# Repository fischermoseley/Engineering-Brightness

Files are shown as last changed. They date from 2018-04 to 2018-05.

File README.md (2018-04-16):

# Engineering-Brightness
1.3 billion people across the world lack a source of artificial lighting, and are unable to safely leave thier homes or do work after dark. Often a rudimentary kerosene lamp is used, but carbon monoxide and combustion byproducts build up in the air, leading to death in some cases. Kerosene is also very expensive, and provides little useful light. 

Engineering Brightnes is a program designed to provide free, safe, and reliable artifical lighting to the world. 

Originally started at Preston Middle School, Colorado Early Colleges Fort Collins is currently prototyping a new design, and the files are available here. The electrical system has been sucessfully prototyped, and the mechanical enclosure is currently under development.

More information is available at http://philanthropic-engineering.org/

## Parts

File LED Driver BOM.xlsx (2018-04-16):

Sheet: Rev A
Part | Value | Device | Package | Description | Digikey PN
IC1 | 2.5V | LM4040DYM3-2.5-TR | SOT-23-3 | 2.5V Reference | 576-1047-1-ND
R1 | 0.1R | CSR1206FTR100 | 1206 | 0.1R Shunt Resistor | CSR1206FTR100CT-ND
R2 | 91k | RC0603JR-0791KL | 0603 | 91k Resistor | 311-91KGRCT-ND
R3 | 10k | RC0603FR-0710KL | 0603 | 10k Resistor | 311-10.0KHRCT-ND
R4 | 1.5k | RNCP0603FTD1K50 | 0603 | 1.5k Resistor | RNCP0603FTD1K50CT-ND
U1 |  | SI4712DY | SO8 | Rail-to-Rail Opamp | SI4712DY-T1-GE3CT-ND
U2 |  | MC3320DR2G | 8SOIC | Rail-to-Rail Opamp | MC33202DR2GOSCT-ND

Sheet: Rev B
Onboard:
Part | Value | Device | Package | Description | Digikey PN | Unit Price | Quantity per Board | Cost per Board | Notes | Link
IC1 | 2.5V | LM4040DYM3-2.5-TR | SOT-23-3 | 2.5V Reference | 576-1047-1-ND | 0.7740 | 1 | 0.7740
R1 | 0.1R | CSR1206FTR100 | 1206 | 0.1R Shunt Resistor | CSR1206FTR100CT-ND | 0.2424 | 1 | 0.2424
R2 | 240k | RMCF0603JT240K | 0603 | 240k Resistor | RMCF0603JT240KCT-ND | 0.0130 | 1 | 0.0130
R3 | 10k | RC0603FR-0710KL | 0603 | 10k Resistor | 311-10.0KHRCT-ND | 0.0150 | 1 | 0.0150
R4 | 1.5k | RNCP0603FTD1K50 | 0603 | 1.5k Resistor | RNCP0603FTD1K50CT-ND | 0.0300 | 1 | 0.0300
U1 |  | SI4712DY | SO8 | Rail-to-Rail Opamp | SI4712DY-T1-GE3CT-ND | 0.8130 | 1 | 0.8130
U2 |  | MC3320DR2G | 8SOIC | Rail-to-Rail Opamp | MC33202DR2GOSCT-ND | 0.7740 | 1 | 0.7740
J1 | JST-RCY-Female | eBoot 20 AWG JST Plug Connector 2 Pin Male Female Plug Connector Cable Wire for LED Lamp Strip RC Toys Battery, 10 Pairs | PTH | Power Input Connector | (Amazon) | 0.1623 | 1 | 0.1623
J2 |  |  | PTH | Power Output Connector | (RapidLED) |  | 1
J3 | JST-SM-Female | HKBAYI 50Pair / 50sets 3 pin JST SM Male Female plug LED Connector Cable For WS2812B WS2812 WS2811 LED Strip Lamp with 15cm Long Wire | PTH | Dimming Pot Connector | (Amazon) | 0.1200 | 1 | 0.1200
Offboard:
Part | Value | Device | Package | Description | Digikey PN | Unit Price | Quantity per Board | Cost per Board | Notes | Link
R5 | 100k | P110KV1-1F15BR100K | Panel Mount | Dimming Potentiometer | 987-1394-ND | 0.7560 | 1 | 0.7560
J4 | JST-SM-Male | HKBAYI 50Pair / 50sets 3 pin JST SM Male Female plug LED Connector Cable For WS2812B WS2812 WS2811 LED Strip Lamp with 15cm Long Wire | PTH | Dimming Pot Connector | (Amazon) | 0.1200 | 1 | 0.1200
Board |  |  |  |  | (PCBway) | 0.6400 | 1 | 0.6400
All Unit Costs evaluated at a quantity of 25 |  |  |  |  |  |  | Total Cost per Board | 4.4596

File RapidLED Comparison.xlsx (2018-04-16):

Name | Solderless? | Color | Forward Voltage | Current | Power Consumption | Luminous Output | Cost | lm/W | lm/W/$
XM-L2 | No | Cool | 2.85 | 0.7 | 1.995 | 364 | $5 | 182.4561404 | 36.49122807
XM-L2 | Yes | Cool | 2.85 | 0.7 | 1.995 | 364 | $5.50 | 182.4561404 | 33.1738437
XP-G3 | No | Cool | 2.83 | 0.35 | 0.9905 | 179 | $4 | 180.7168097 | 45.17920242
XP-G3 | Yes | Cool | 2.83 | 0.35 | 0.9905 | 179 | $4.25 | 180.7168097 | 42.52160228
Rebel ES | Yes | Cool | 3.1 | 0.7 | 2.17 | 235 | $1.75 | 108.2949309 | 61.88281764
XM-L2 | No | Neutral | 2.85 | 0.7 | 1.995 | 318 | $5 | 159.3984962 | 31.87969925
XM-L2 | Yes | Neutral | 2.85 | 0.7 | 1.995 | 318 | $5.50 | 159.3984962 | 28.98154477
XP-G3 | No | Neutral | 2.83 | 0.7 | 1.981 | 179 | $4 | 90.35840485 | 22.58960121
XP-G3 | Yes | Neutral | 2.83 | 0.7 | 1.981 | 179 | $4.25 | 90.35840485 | 21.26080114
XP-L2 | No | Neutral | 2.82 | 1.05 | 2.961 | 527 | $6.25 | 177.980412 | 28.47686592
XP-L2 | Yes | Neutral | 2.82 | 1.05 | 2.961 | 527 | $6.50 | 177.980412 | 27.38160185
XP-G2 | No | Warm | 3 | 1 | 3 | 125 | $4 | 41.66666667 | 10.41666667
XP-G2 | Yes | Warm | 3 | 1 | 3 | 125 | $4 | 41.66666667 | 10.41666667
XM-L2 | No | Warm | 2.85 | 0.7 | 1.995 | 273 | $5 | 136.8421053 | 27.36842105
XM-L2 | Yes | Warm | 2.85 | 0.7 | 1.995 | 273 | $5.50 | 136.8421053 | 24.88038278
XP-G3 | No | Warm | 2.83 | 0.35 | 0.9905 | 179 | $4.00 | 180.7168097 | 45.17920242
XP-G3 | Yes | Warm | 2.83 | 0.35 | 0.9905 | 179 | $4.25 | 180.7168097 | 42.52160228
XP-L2 | No | Warm | 2.82 | 1.05 | 2.961 | 505 | $6.25 | 170.5504897 | 27.28807835
XP-L2 | Yes | Warm | 2.82 | 1.05 | 2.961 | 505 | $6.50 | 170.5504897 | 26.23853688

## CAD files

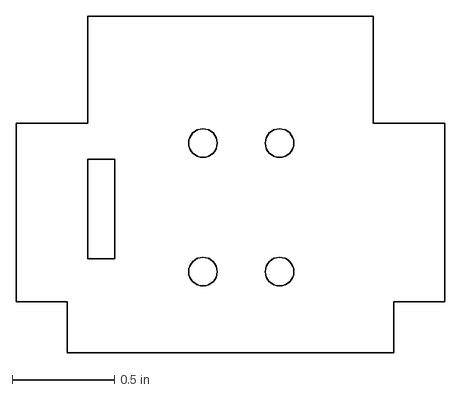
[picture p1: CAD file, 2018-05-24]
LED-Driver-Mylar/LED Reflector.dxf
2.10 x 1.65 in

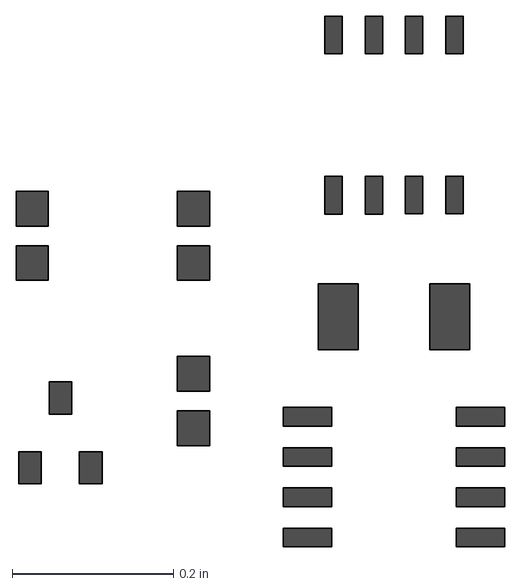
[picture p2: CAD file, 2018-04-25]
LED-Driver-Stencil/LED Driver Stencil.dxf
0.607 x 0.659 in

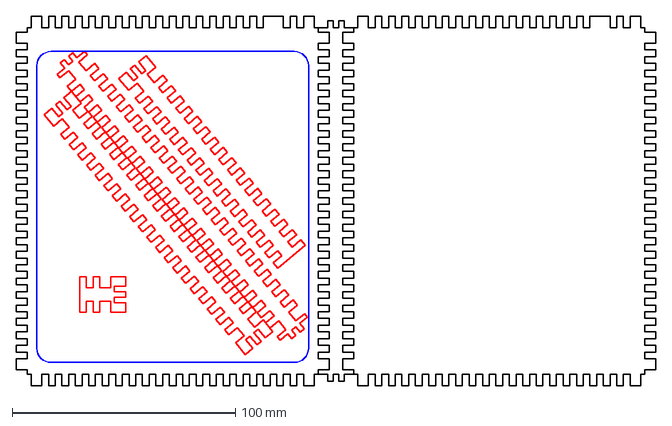
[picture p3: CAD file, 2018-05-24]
Solar-Panel-Case/5mm Solar Panel Case.dxf
286.9 x 165.5 mm

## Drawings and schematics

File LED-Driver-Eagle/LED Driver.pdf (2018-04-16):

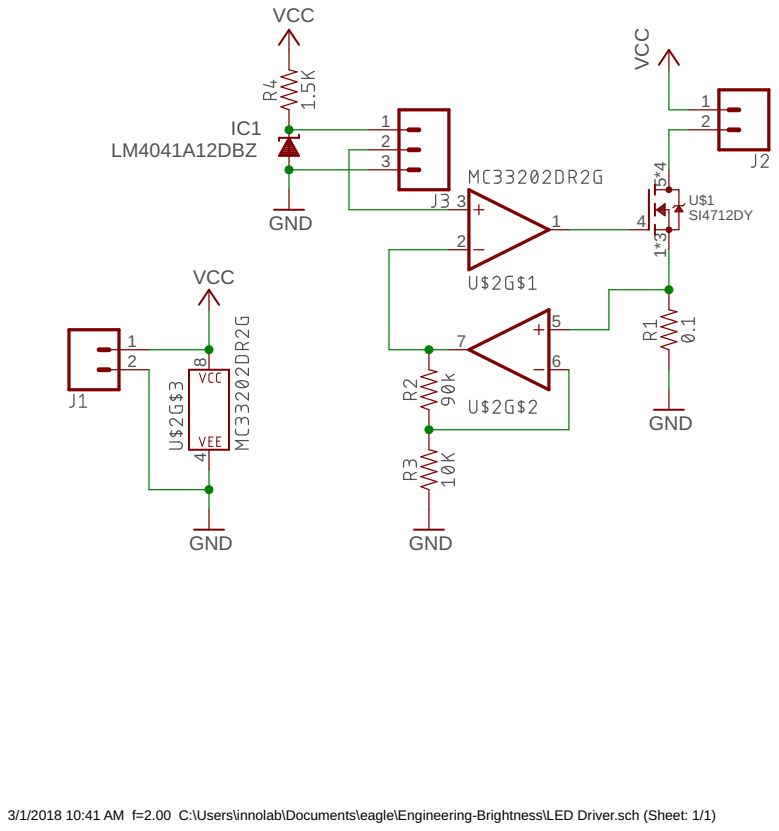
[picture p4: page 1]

3/1/2018 10:41 AM f=2.00 C:\Users\innolab\Documents\eagle\Engineering-Brightness\LED Driver.sch (Sheet: 1/1)

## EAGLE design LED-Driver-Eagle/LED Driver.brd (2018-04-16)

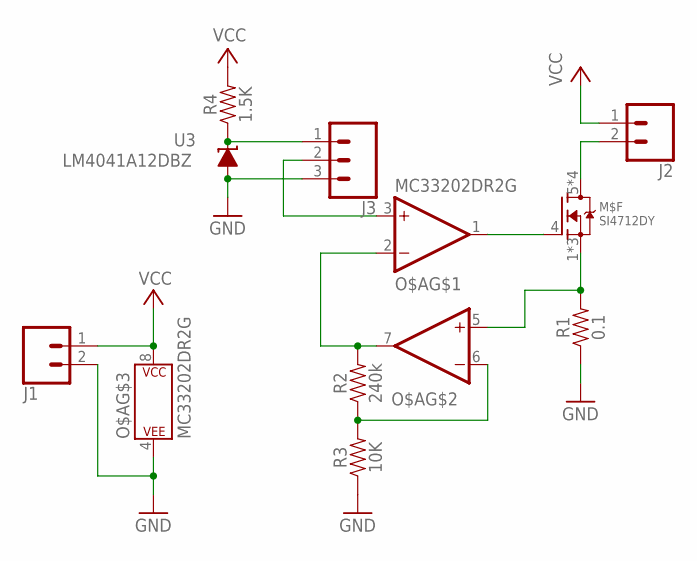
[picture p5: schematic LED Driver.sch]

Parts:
J1, J2: CONN_02PTH4; 1X02_XTRA_BIG
J3: CONN_03; 1X03
M$F: SI4712DY; SO8
O$A: MC33202DR2G; SOIC8
R1: 0.1; 1210
R2: 240k; 0603
R3: 10K; 0603
R4: 1.5K; 0603
U3: LM4041A12DBZ; DBZ_R-PDSO-G3

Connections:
GND: J1.2, J3.3, O$A.4 (P$V-), R1.1, R3.1, U3.2 (A)
unnamed: J3.1, R4.1, U3.1 (C)
unnamed: J3.2, O$A.3 (+IN)
unnamed: M$F.4 (G), O$A.1 (OUT)
unnamed: J2.2, M$F.5 (D), M$F.6 (D), M$F.7 (D), M$F.8 (D)
unnamed: M$F.1 (S), M$F.2 (S), M$F.3 (S), O$A.5 (+IN), R1.2
unnamed: O$A.2 (-IN), O$A.7 (OUT), R2.2
unnamed: O$A.6 (-IN), R2.1, R3.2
VCC: J1.1, J2.1, O$A.8 (P$V+), R4.2

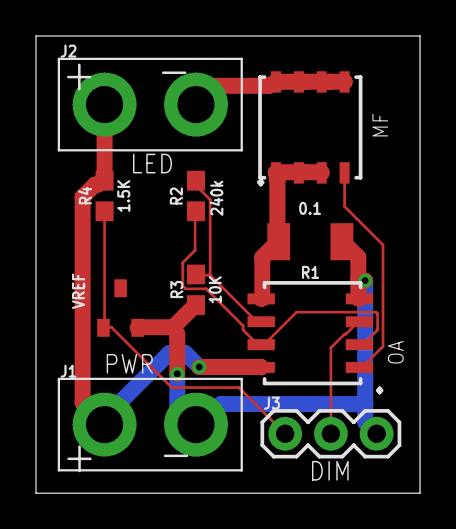
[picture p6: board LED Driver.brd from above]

Board: 2 copper layers, 21.3 x 25.4 mm, 10 parts (0 on the bottom side), 9 nets.

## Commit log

2018-03-02 Added gerbers sent to OSHPark
2018-03-23 Updated BOM for Revision B
    [LED Driver BOM.xlsx]
2018-03-23 Added LED Comparison Chart
    [RapidLED Comparison.xlsx]
2018-03-23 Updated LED Driver BOM
    Forgot that the output connector is supplied by RapidLED
    [LED Driver BOM.xlsx]
2018-03-26 Fixed board asthetics
    Added labels for input terminals, fixed logo, changed text to Revision B
    [LED Driver.brd, LED Driver.sch]
2018-03-26 Reordered file structure
    Added folders for eagle files, fixed readme, deleted unnecessary file
    [LED Driver.brd, LED Driver.sch]
2018-03-26 Added Gerbers
    Processes using OSHpark 2-layer
2018-03-26 Fixed gerbers
    Accidentally zipped a folder containing the files, not the files themselves
2018-03-27 Fixed Gerbers
    CAM job wasn't processed with OSHpark processor, switched to thier 2 layer
2018-03-27 Added U3 Label
    Added label for U3 (vref) and updated gerbers
    [LED Driver.brd, LED Driver.sch]
2018-03-27 Added CECFC on bottom of board
    [LED Driver.brd]
2018-03-27 Pushed to Fusion
    [LED Driver.brd]
2018-03-30 Changed U1 and U2 to MF and OA
    Updated Gerbers and eagle board files
    [LED Driver.brd, LED Driver.sch]
2018-04-16 Removed spurious gerbers
2018-04-25 Added DXF for the stencil
    [LED Driver Stencil.dxf]
2018-04-25 Reorganized stencil files
    [LED Driver Stencil.dxf]
2018-05-24 Added solar panel case and mylar cutout
    [5mm Solar Panel Case.dxf, LED Reflector.dxf]

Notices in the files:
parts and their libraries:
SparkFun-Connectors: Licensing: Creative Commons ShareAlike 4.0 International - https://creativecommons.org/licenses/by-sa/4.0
